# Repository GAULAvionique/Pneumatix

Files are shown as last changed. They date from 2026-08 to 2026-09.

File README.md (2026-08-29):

<!--"""[![MasterHead](Documentation/GAUL/logo-full.webp)](https://gaulspace.web.app/home)-->

<h1 align="center">Projet Pneumatix - GAUL 2024-2025</h1>



<p align="left">
  <a href="https://www.facebook.com/gaul.ul" target="_blank">
    GAUL Facebook
  </a>
  <a href="https://www.instagram.com/gaul.ul/" target="_blank">
    GAUL Instagram
  </a>
  <a href="https://www.facebook.com/groupeaerospatialul/" target="_blank">
    GAUL Youtube
  </a>
</p>

## 🌟 **Projet Pneumatix**

Pneumatix est un **module de communication et de télémétrie séparé** développé par le GAUL pour assurer un relais de données fiable entre les systèmes embarqués de la fusée et la station au sol. Conçu comme une carte fille (PCB de communication) isolée du PCB principal, le système garantit une intégrité maximale des signaux RF.

Le projet est conçu pour être :

*   Performant sur de longues distances (Module LoRa 433MHz)
*   Modulable avec un contrôle matériel des états (M0/M1) manuellement
*   Robuste face aux interférences électromagnétiques et à l'effet Doppler

L’objectif principal de Pneumatix est d'assurer une liaison de télémétrie fiable (comparée au RFD900X).

---

## 📦 **Fonctionnalités Intégrées**

Le système centralise l'infrastructure de communication externe et inclut :

*   **Communication Radio LoRa**
    Intégration du module EBYTE E22-400T33S avec routage d'antenne SMA 50 ohms pour une portée maximale et gestion des canaux LBT (Listen Before Talk).
*   **Microcontrôleur (Optionnel / Déporté)**
    Interfaçage direct avec le STM32F4 de ODBlix via des signaux logiques 3.3V natifs ou possibilité de programmer seul.
*   **Contrôle de Mode Matériel**
    Configuration des modes de fonctionnement (Normal, WOR, Configuration, Veille) via des *solder jumpers* sur les broches M0 et M1.
*   **Indicateurs de statut**
    Diagnostic visuel via des LEDs dédiées pour l'alimentation 5V et l'état d'occupation du buffer série (broche AUX).

---

## 🛰 **Architecture du Projet**

Le dépôt contient l’ensemble des éléments matériels et logiciels nécessaires au déploiement du module :

*   Schémas de conception PCB (Routage RF)
*   Scripts de configuration des registres LoRa
*   Documentation technique

---

## 📚 **Documentation**

La documentation complète des pièces du projet est disponible dans le dossier `Documentation/`.

---

## ⚙ **Compilation et Déploiement**

Le code d'interfaçage est développé autour de l’écosystème ODBLix pour communiquer avec le module.

### Compilation

```bash
git clone [https://github.com/GAULAvionique/Pneumatix.git](https://github.com/GAULAvionique/Pneumatix.git)

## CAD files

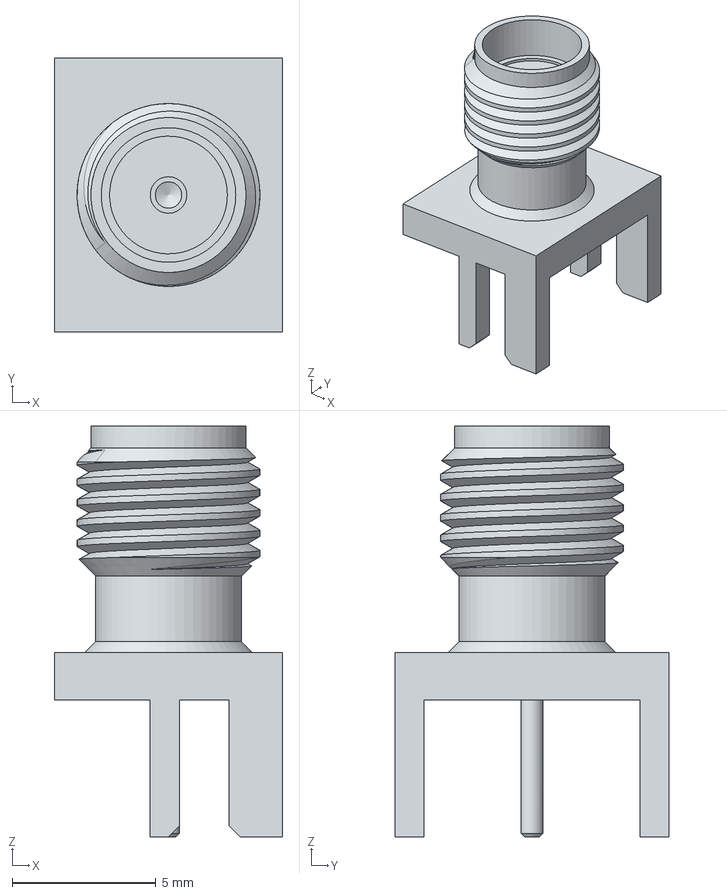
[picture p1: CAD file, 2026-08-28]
Kicad/Components/142_0701_801/142-0701-801.step
7.92 x 9.53 x 14.3 mm

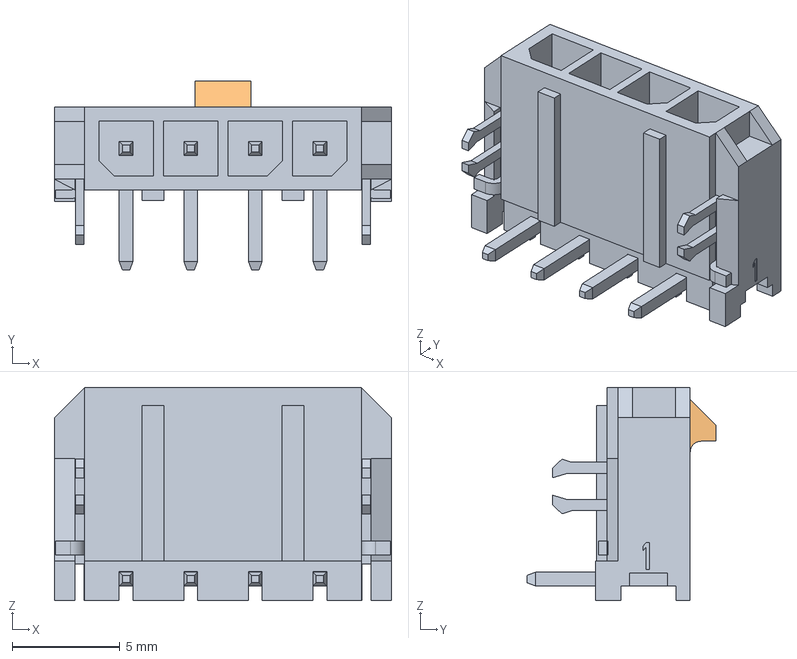
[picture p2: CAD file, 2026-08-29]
Kicad/Components/436500404/436500404.step
15.7 x 8.79 x 9.90 mm

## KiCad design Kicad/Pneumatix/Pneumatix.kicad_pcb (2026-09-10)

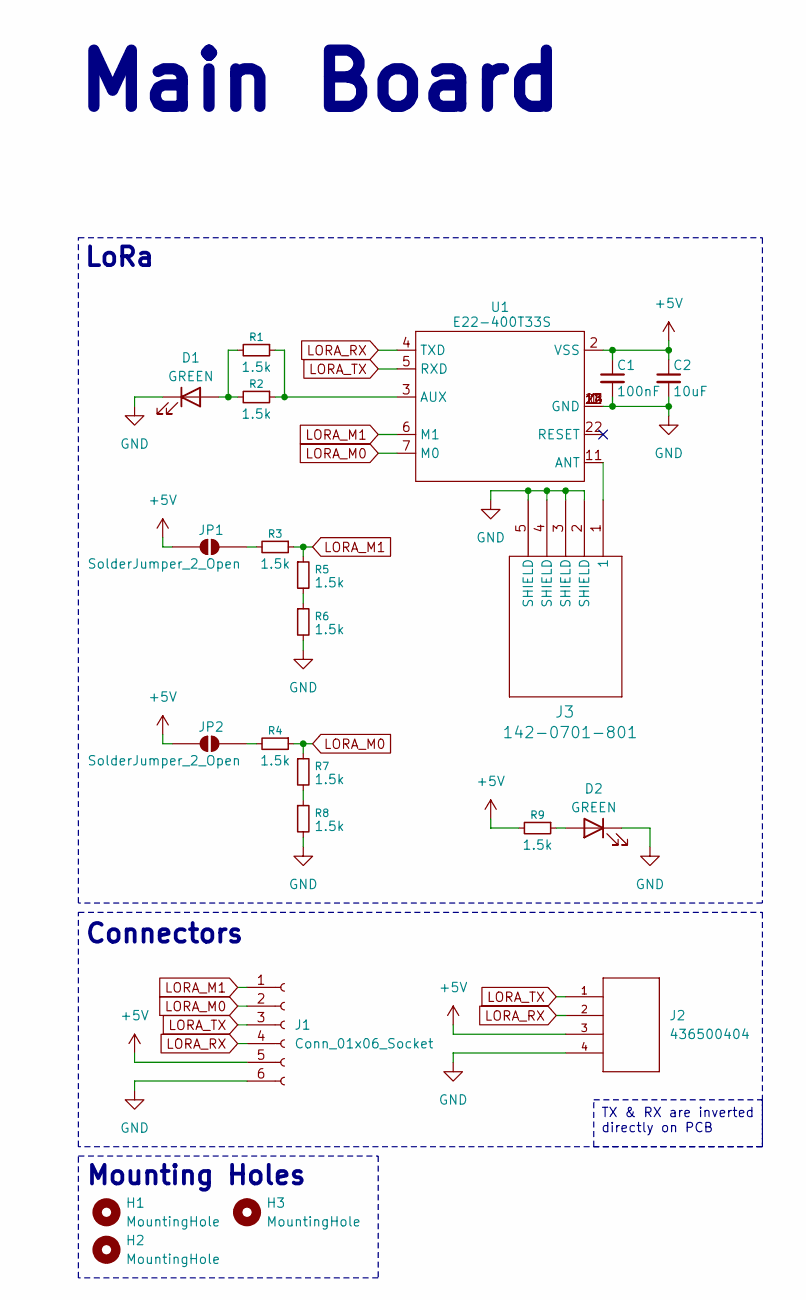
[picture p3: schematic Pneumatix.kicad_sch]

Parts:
C1: 100nF; C_0603_1608Metric
C2: 10uF; C_0603_1608Metric
D1, D2: GREEN; LED_0603_1608Metric
H1, H2, H3: MountingHole; MountingHole_3.2mm_M3
J1: Conn_01x06_Socket; PinHeader_1x06_P2.00mm_Vertical
J2: 436500404; CONN_SD-43650-002_04_MOL; MANUFACTURER_PART_NUMBER 436500404
J3: 142-0701-801; CONN_142-0701-801
JP1, JP2: SolderJumper_2_Open; SolderJumper-2_P1.3mm_Open_TrianglePad1.0x1.5mm
R1, R2, R3, R4, R5, R6, R7, R8, R9: 1.5k; R_0603_1608Metric
U1: E22-400T33S; E32-433T33S

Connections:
+5V: C1.1, C2.1, J1.5, J2.3, JP1.2 (B), JP2.2 (B), R9.2, U1.2 (VSS)
GND: C1.2, C2.2, D1.1 (K), D2.1 (K), J1.6, J2.4, J3.2 (SHIELD), J3.3 (SHIELD), J3.4 (SHIELD), J3.5 (SHIELD), R6.2, R8.2, U1.0 (GND), U1.1 (GND), U1.12 (GND), U1.13 (GND), U1.14 (GND), U1.23 (GND)
LORA_M0: J1.2, R4.1, R7.1, U1.7 (M0)
LORA_M1: J1.1, R3.1, R5.1, U1.6 (M1)
LORA_RX: J1.4, J2.2, U1.4 (TXD)
LORA_TX: J1.3, J2.1, U1.5 (RXD)
unnamed: D1.2 (A), R1.2, R2.2
unnamed: D2.2 (A), R9.1
unnamed: JP1.1 (A), R3.2
unnamed: JP2.1 (A), R4.2
unnamed: R5.2, R6.1
unnamed: R7.2, R8.1
unnamed: J3.1, U1.11 (ANT)
unnamed: R1.1, R2.1, U1.3 (AUX)

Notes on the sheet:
Connectors
Main Board
LoRa
Mounting Holes
TX & RX are inverted directly on PCB

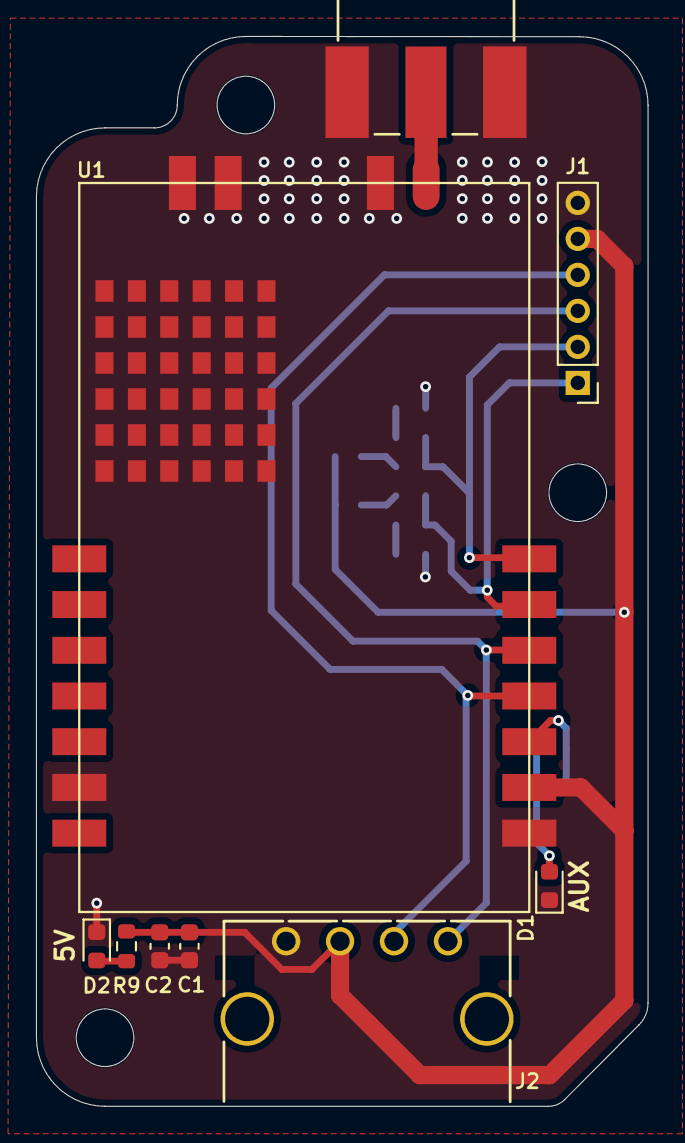
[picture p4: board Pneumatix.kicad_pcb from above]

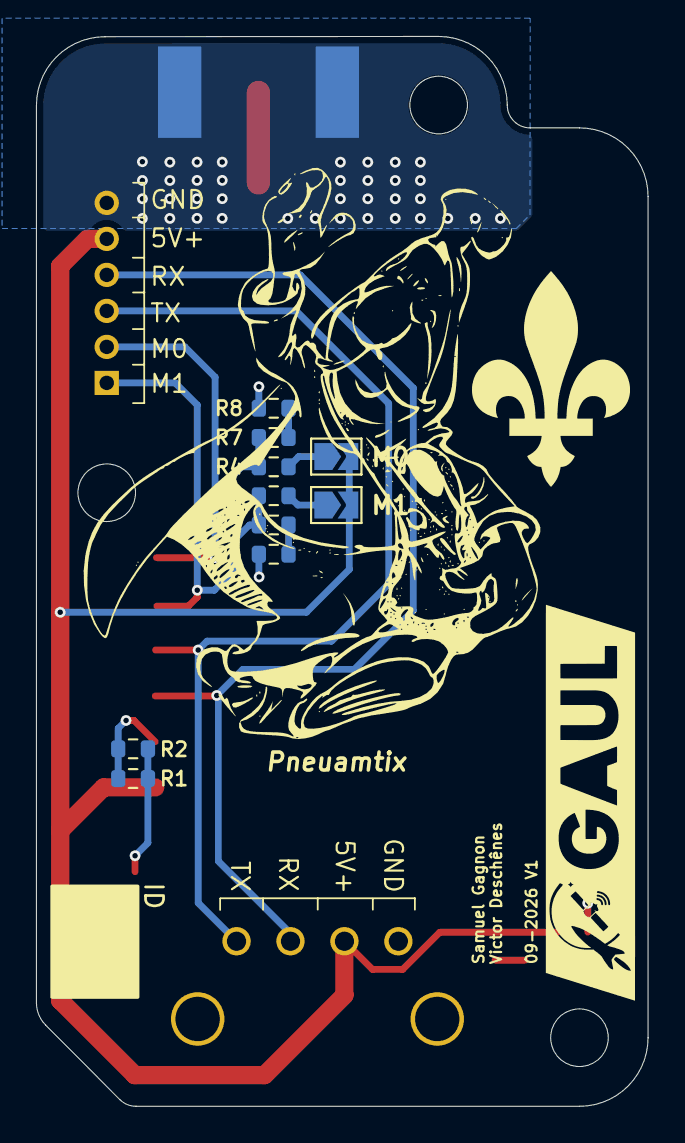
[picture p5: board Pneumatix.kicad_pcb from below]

Board: 2 copper layers, 34.0 x 59.4 mm, 22 parts (10 on the bottom side), 14 nets.

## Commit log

2026-08-28 wip: schematic, footprints/symbols
    [142-0701-801.step, 705430004.stp, E22-XXXT30、33S.PcbLib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]
2026-08-29 wip: pcb and conception notes, fix: change molex 5 pins to 4 pins
    [436500404.step, 705430004.stp, Pneumatix.kicad_pcb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]
2026-08-29 wip: pcb components
    [Pneumatix.kicad_pcb, Pneumatix.kicad_sch]
2026-08-30 wip: pcb traces and plane
    [Pneumatix.kicad_pcb]
2026-08-30 wip: ajust e22 position and add silkscreen
    [Pneumatix.kicad_pcb]
2026-08-31 wip: add thermal pads and plane for heat dissipation
    [Pneumatix.kicad_pcb, Pneumatix.kicad_sch]
2026-09-02 wip: add pu/pd for M0 and M1, remake traces and swap gnd/signal/passive components plane
    [Pneumatix.kicad_pcb, Pneumatix.kicad_sch]
2026-09-04 wip: fix voltage divider for m0 and m1, reduce 2.54 debug header to 2.00mm
    [Pneumatix.kicad_pcb, Pneumatix.kicad_sch]
2026-09-04 FIX: fixed 5V trace cutting ground plane and minor routing rework
    [Pneumatix.kicad_pcb]
2026-09-10 wip: silkscreen and adjustements
    [Pneumatix.kicad_pcb, Pneumatix.kicad_sch]
2026-10-22 wip: pcb adjustements
